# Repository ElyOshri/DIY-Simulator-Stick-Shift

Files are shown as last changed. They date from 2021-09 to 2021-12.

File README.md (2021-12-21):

# DIY-Simulator-Stick-Shift




A 3D Printed DIY Simulator Stick Shift Using Potentiometers And Arduino Nano Or ESP32

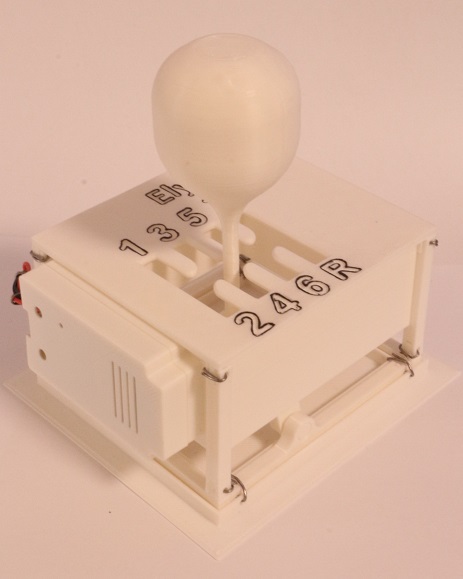
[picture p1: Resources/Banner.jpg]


## Topics
 - [Tutorial](https://github.com/ElyOshri/DIY-Simulator-Stick-Shift#tutorial)
 - [Tested Boards](https://github.com/ElyOshri/DIY-Simulator-Stick-Shift#tested_boards)
 - [Hardware](https://github.com/ElyOshri/DIY-Simulator-Stick-Shift#hardware)
 - [Credits](https://github.com/ElyOshri/DIY-Simulator-Stick-Shift#credits)

## Tutorial:
Download the hardware and firmware folders from [releases](https://github.com/ElyOshri/DIY-Simulator-Stick-Shift/releases). Start printing the parts from the hardware folder according to 3d printing list from [Hardware](#Hardware:) (some of the parts need support).

After you finish printing the Base, Hinge and the Main Stick you can start assembling the parts ([use this 3d model for reference](https://a360.co/3D5aO7Y)) ,
then insert the potentiometers to they're spots and wire them to your board according to this wiring diagram 
([Arduino Nano](https://user-images.githubusercontent.com/79017393/132395478-2bf8ad6f-0b95-429a-84c2-f516c4f6ddcb.png), 
[ESP32](https://user-images.githubusercontent.com/79017393/132395408-584d270a-1471-4dd1-976c-bccc9487b785.png) (for ESP32 use 3V3 instead of 5V)) You can look at the firmware for the exact pins that i used. 

After you wired everything up you can start uploading the firmware by choosing the correct file in the Firmware folder, changing the pins in the code, choosing your board and downloading all of the drivers and libraries necessary you can start uploading the firmware.(some boards needs you to press a button on them while uploading firmware)
* Note that for each board its going to be different and you may need to install libraries and drivers for your board (the links for the libraries and drivers are at the top of the file)
* In the serial monitor your need to set the baud rate to `115200` to see the correct values

Then check the serial monitor move the gear lever into each position and start assigning the rows values, then upload the firmware again and you should be finished.

**Here Are Some Good Tutorial To Help You With All Of This:**
- [Arduino Nano Original Guide](https://www.arduino.cc/en/Guide/ArduinoNano)
- [Arduino Nano Clone Driver](https://electropeak.com/learn/how-to-install-ch340-driver/)
- [ESP32 Driver And Guide](https://randomnerdtutorials.com/installing-the-esp32-board-in-arduino-ide-windows-instructions/)
- [Installing a Library](https://www.arduino.cc/en/guide/libraries)

## Tested_Boards:
```
* Arduino Nano
* ESP-WROOM-32
```

## Hardware:

* Arduino Nano or ESP32 (ESP32 for Bluetooth)
* WL b10k ohm Potentiometer (2x)
* 1mm or thinner metal wire (solder or paper clips can be used)
* 26 gauge or bigger electrical wire (2 meters should be enough)
* USB cable (depending on your board)
* Solder or a crimping set (JST connectors 5 pin JST-XH 2.54mm should work) 
* 3d printer filament (PLA or another ridged filament)

**3D Printed Parts:**
* Bottom Hinge
* Top Hinge
* Main Stick
* Base Right
* Base Left
* Base Top
* Base Bottom
* H Frame
* Right Frame / + Arduino Nano Case (depends on your board)
* Left Frame / + ESP32 Case (depends on your board)
* Base Attachment (optional)
* Case Cover ESP32/Arduino Nano (optional and depends on your board)

**Tools:**
* Soldering Iron / Crimping Set
* 3D Printer / A way to get the parts
* A computer with a USB port and the Arduino IDE app to program the board

## Credits
* Arduino Joystick Library (By: MHeironimus): https://github.com/MHeironimus/ArduinoJoystickLibrary
* ESP32 Gamepad Library (By: lemmingDev): https://github.com/lemmingDev/ESP32-BLE-Gamepad
* ESP32 Case (By: Antonio Garcia): https://www.thingiverse.com/thing:2071188
* Arduino Nano Case (By: Jonathan Prive): https://www.thingiverse.com/thing:4850125

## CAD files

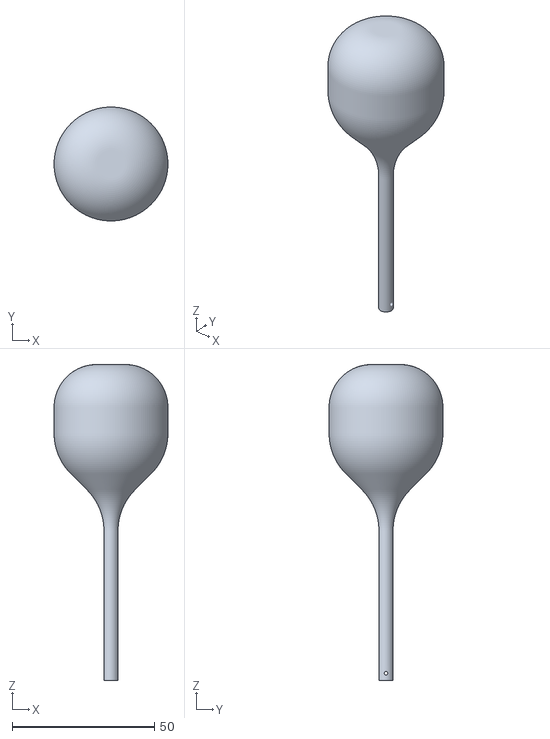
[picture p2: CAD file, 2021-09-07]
Hardware/Main Stick.stl
40.0 x 40.0 x 111.0

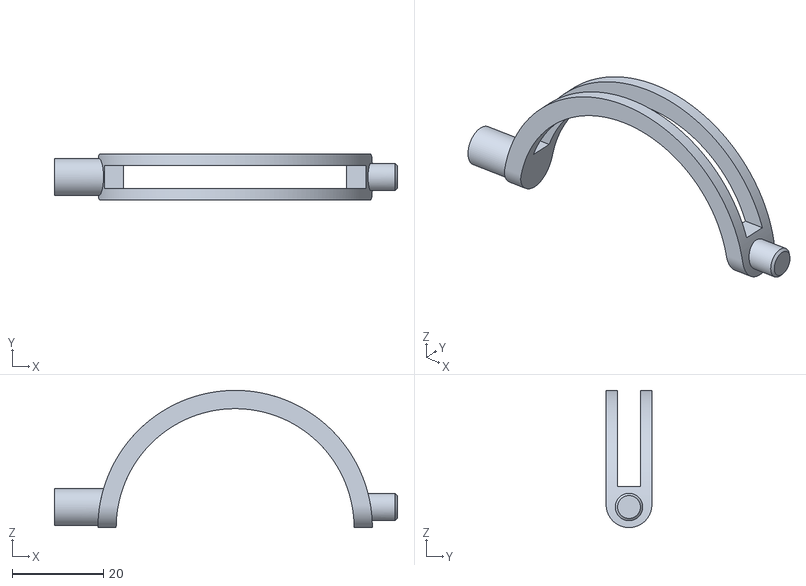
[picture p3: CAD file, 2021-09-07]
Hardware/Top Hinge.stl
75.0 x 10.0 x 30.0

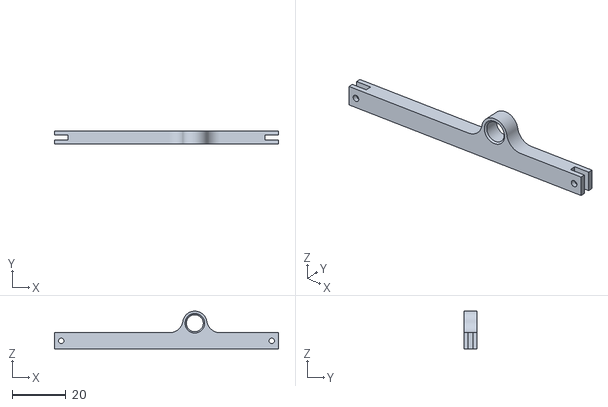
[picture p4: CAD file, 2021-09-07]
Hardware/Base Bottom.stl
83.0 x 5.00 x 14.0

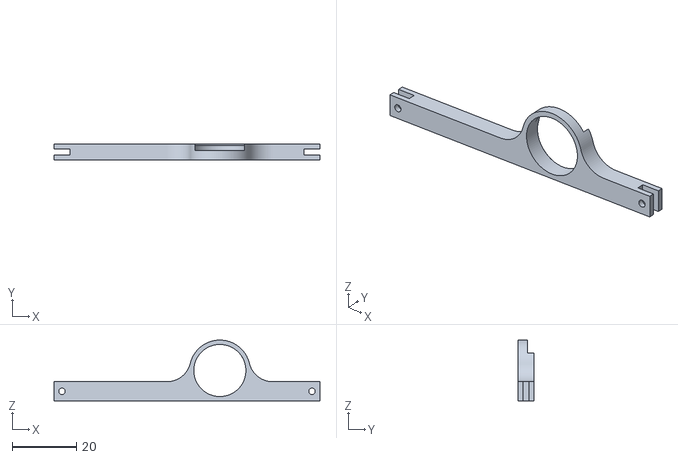
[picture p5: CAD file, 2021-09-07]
Hardware/Base Top.stl
83.0 x 5.00 x 19.0

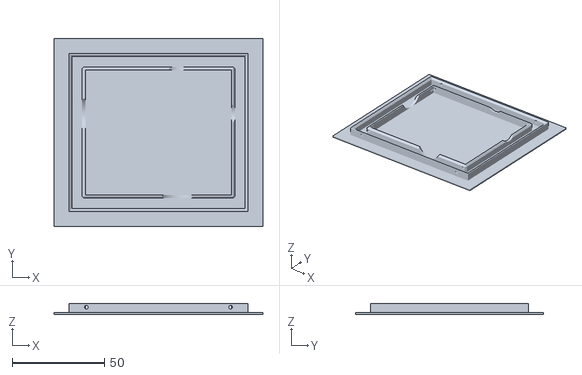
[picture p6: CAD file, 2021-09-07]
Hardware/Base Attachment.stl
113.0 x 101.5 x 6.00

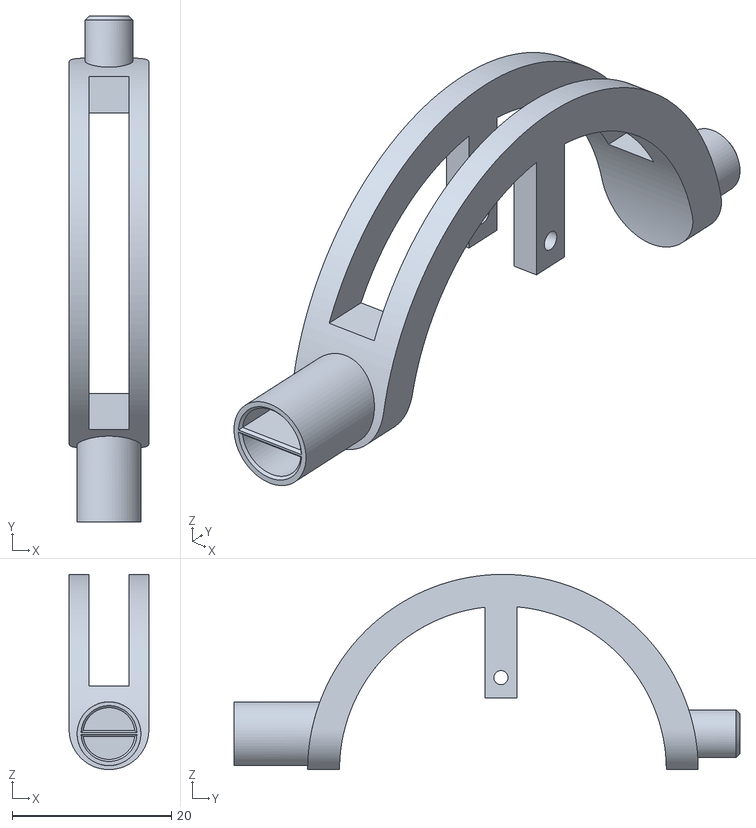
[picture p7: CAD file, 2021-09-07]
Hardware/Bottom Hinge.stl
10.0 x 63.5 x 24.5

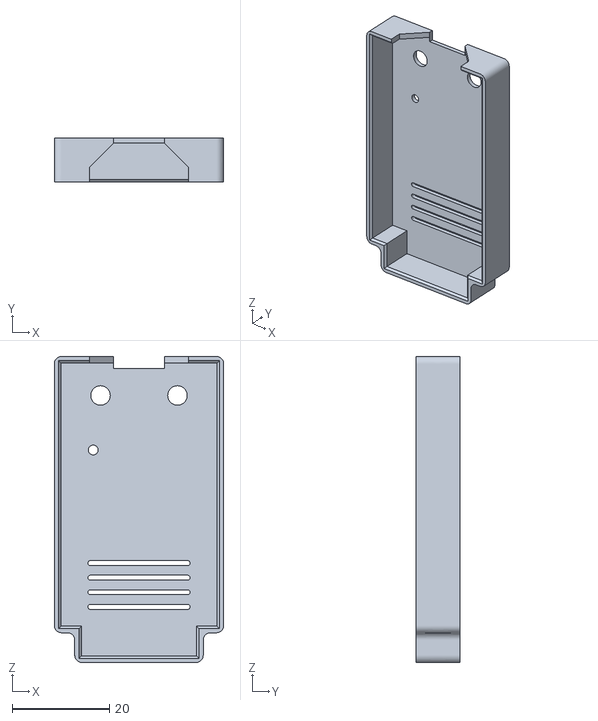
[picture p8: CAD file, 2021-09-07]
Hardware/ESP32 Case Cover.stl
34.8 x 9.00 x 62.8

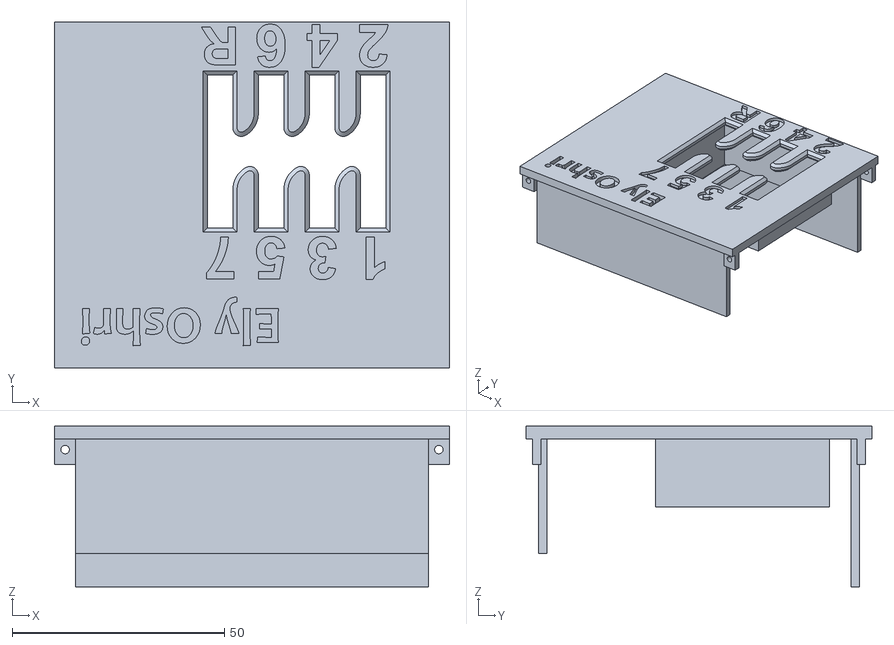
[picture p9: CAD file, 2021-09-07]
Hardware/H Frame.stl
93.0 x 81.5 x 37.8

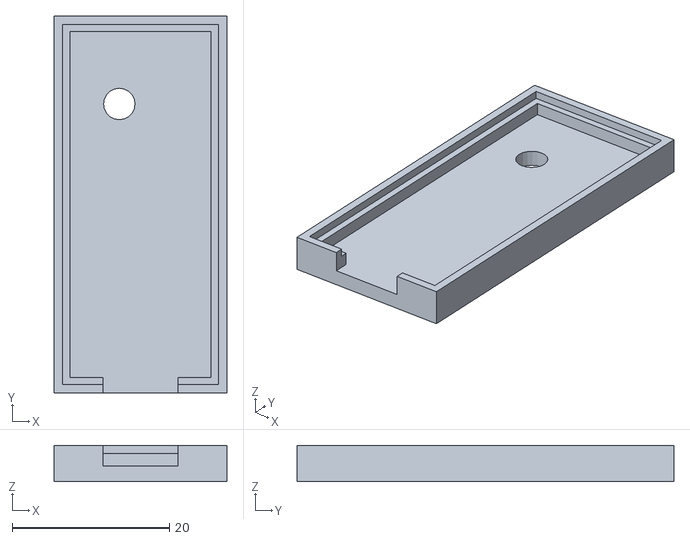
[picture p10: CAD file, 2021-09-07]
Hardware/Arduino Nano Case Cover.stl
22.0 x 48.0 x 4.60

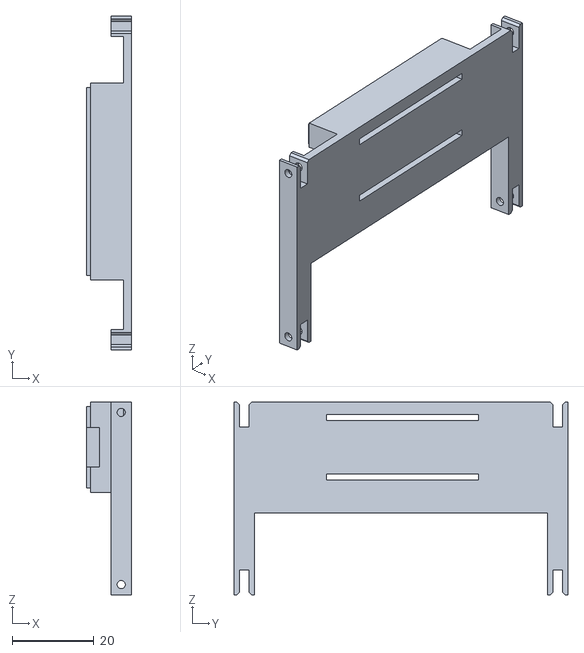
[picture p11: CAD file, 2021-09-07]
Hardware/Right Frame + Arduino Nano Case.stl
11.0 x 81.5 x 47.0

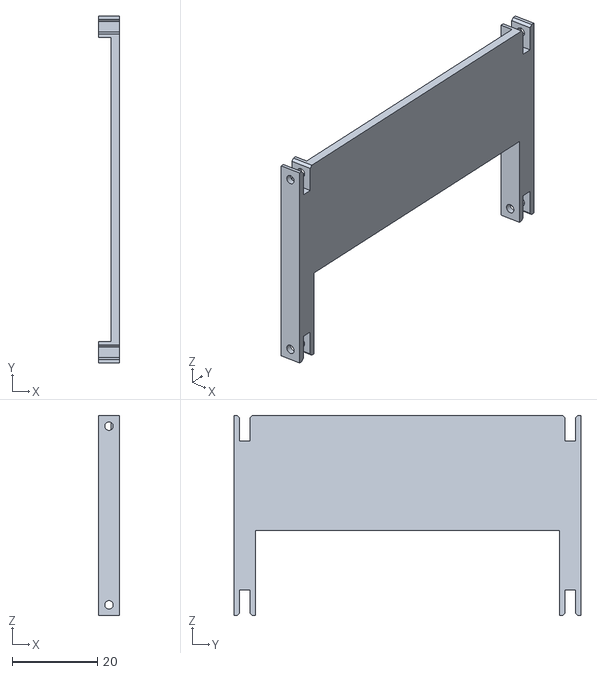
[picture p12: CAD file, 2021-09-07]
Hardware/Right Frame.stl
5.00 x 81.5 x 47.0

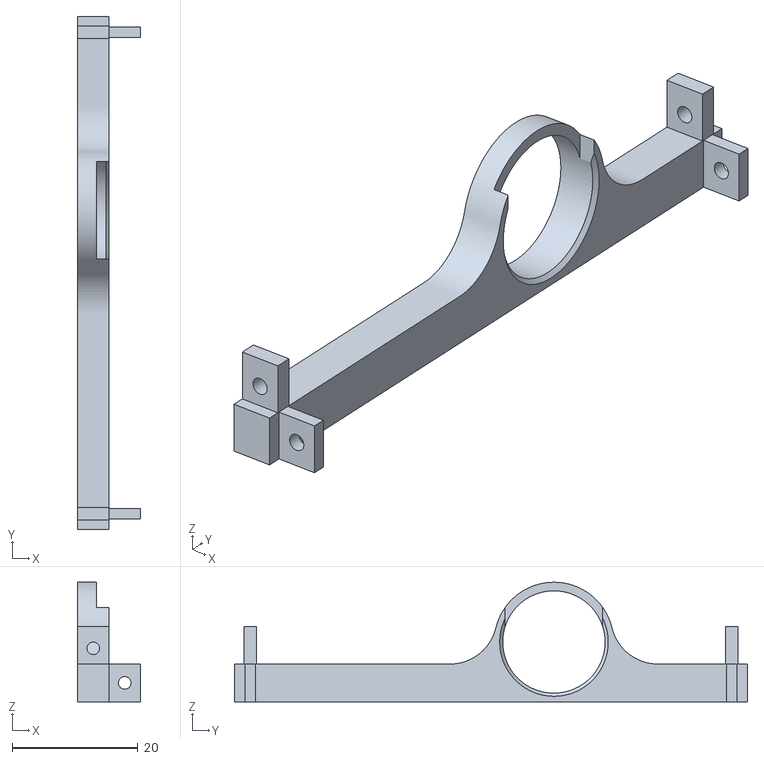
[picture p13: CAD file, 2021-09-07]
Hardware/Base Right.stl
10.0 x 81.5 x 19.0

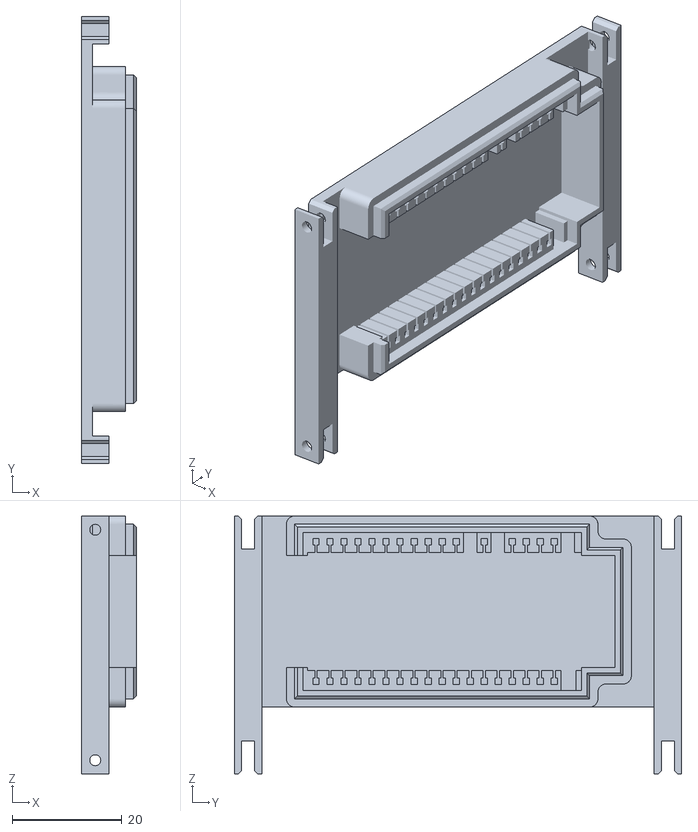
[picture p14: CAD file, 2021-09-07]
Hardware/Left Frame + ESP32 Case.stl
10.0 x 81.5 x 47.0

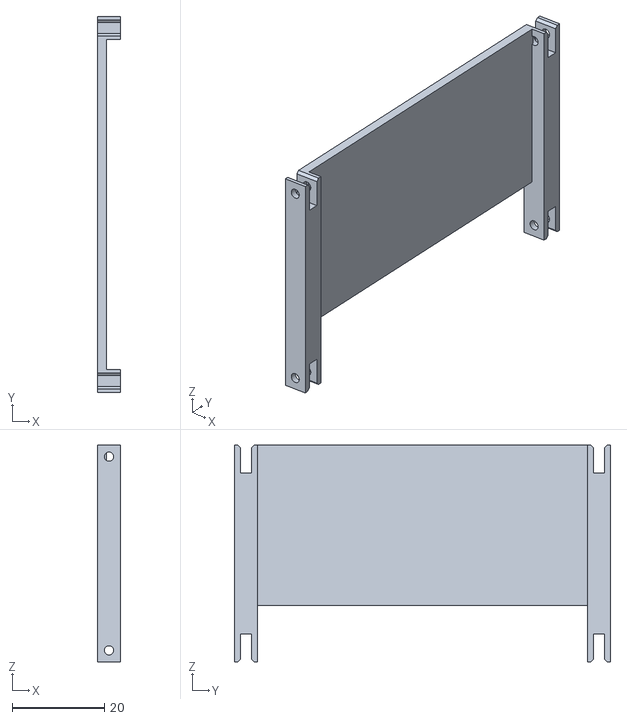
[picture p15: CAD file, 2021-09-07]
Hardware/Left Frame.stl
5.00 x 81.5 x 47.0

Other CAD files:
Hardware/Base Left.stl

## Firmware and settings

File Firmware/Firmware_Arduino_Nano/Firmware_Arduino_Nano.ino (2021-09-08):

//Arduino NANO CODE
//Joystick library is https://github.com/MHeironimus/ArduinoJoystickLibrary
//Arduino Nano Clone Driver: https://sparks.gogo.co.nz/ch340.html

#define MAX_POT_VALUE 1023 //max potentiometer value (only needed if you flip one of the axis)

#define POT_PIN_Y A6 
#define FLIP_Y false //if you wired the potentiometer wrong you can flip it (true or false)

#define POT_PIN_X A4
#define FLIP_X false //if you wired the potentiometer wrong you can flip it (true or false)

//Y Value
#define TOP_GEAR_ROW 415 //top row of gears max value (Y value < TOP_GEAR_ROW)
#define BOTTOM_GEAR_ROW 475 //bottom row of gears min value (Y value > BOTTOM_GEAR_ROW)


//X Value
#define FIRST_ROW_MAX 385 // 1 and 2 gears row max value (X value < FIRST_ROW_MAX)

#define SECOND_ROW_MIN 405 // 3 and 4 gears row min value (X value > SECOND_ROW_MIN)
#define SECOND_ROW_MAX 450 // 3 and 4 gears row max value (X value < SECOND_ROW_MAX)

#define THIRD_ROW_MIN 465 // 5 and 6 gears row min value (X value > THIRD_ROW_MIN)
#define THIRD_ROW_MAX 485 // 5 and 6 gears row max value (X value < THIRD_ROW_MAX)

#define FOURTH_ROW_MIN 500 // 7 and R/8 gears row max value (X value > FOURTH_ROW_MIN)



#include <Joystick.h>
Joystick_ Joystick;

int currentButton = 8;

int nutralCount = 0;

int potValueY;
int potValueX;


void setup() {
  Serial.begin(115200);
  Joystick.begin();
  Joystick.press(8);
}


void loop() {
  potValueY = analogRead(POT_PIN_Y);
  if (FLIP_Y) {
    potValueY = MAX_POT_VALUE - potValueY;
  }
  potValueX = analogRead(POT_PIN_X);
  if (FLIP_X) {
    potValueX = MAX_POT_VALUE - potValueX;
  }
  Serial.print("Y: ");
  Serial.print(potValueY);
  Serial.print(" X: ");
  Serial.print(potValueX);
  Serial.print(" Button: ");
  Serial.println(currentButton);

  if (Joystick.isConnected()) {
    if (potValueY < TOP_GEAR_ROW && potValueX < FIRST_ROW_MAX) {
      if (currentButton != 0) {
        Joystick.release(currentButton);
        Joystick.press(0);
        currentButton = 0;
        nutralCount = 0;
      }
    }
    else if (potValueY > BOTTOM_GEAR_ROW && potValueX < FIRST_ROW_MAX) {
      if (currentButton != 1) {
        Joystick.release(currentButton);
        Joystick.press(1);
        currentButton = 1;
        nutralCount = 0;
      }
    }
    else if (potValueY < TOP_GEAR_ROW && potValueX > SECOND_ROW_MIN && potValueX < SECOND_ROW_MAX) {
      if (currentButton != 2) {
        Joystick.release(currentButton);
        Joystick.press(2);
        currentButton = 2;
        nutralCount = 0;
      }
    }
    else if (potValueY > BOTTOM_GEAR_ROW && potValueX > SECOND_ROW_MIN && potValueX < SECOND_ROW_MAX) {
      if (currentButton != 3) {
        Joystick.release(currentButton);
        Joystick.press(3);
        currentButton = 3;
        nutralCount = 0;

      }
    }
    else if (potValueY < TOP_GEAR_ROW && potValueX > THIRD_ROW_MIN && potValueX < THIRD_ROW_MAX) {
      if (currentButton != 4) {
        Joystick.release(currentButton);
        Joystick.press(4);
        currentButton = 4;
        nutralCount = 0;
      }
    }
    else if (potValueY > BOTTOM_GEAR_ROW && potValueX > THIRD_ROW_MIN && potValueX < THIRD_ROW_MAX) {
      if (currentButton != 5) {
        Joystick.release(currentButton);
        Joystick.press(5);
        currentButton = 5;
        nutralCount = 0;
      }
    }
    else if (potValueY < TOP_GEAR_ROW && potValueX > FOURTH_ROW_MIN) {
      if (currentButton != 6) {
        Joystick.release(currentButton);
        Joystick.press(6);
        currentButton = 6;
        nutralCount = 0;
      }
    }
    else if (potValueY > BOTTOM_GEAR_ROW && potValueX > FOURTH_ROW_MIN) {
      if (currentButton != 7) {
        Joystick.release(currentButton);
        Joystick.press(7);
        currentButton = 7;
        nutralCount = 0;
      }
    }
    else {
      nutralCount = nutralCount + 1;
      if (pressed == true && currentButton != 8 && nutralCount > 5) {
        Joystick.release(currentButton);
        Joystick.press(8);
        currentButton = 8;
      }
    }
  }
  delay(100);
}

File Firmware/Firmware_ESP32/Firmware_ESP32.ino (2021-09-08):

//ESP32 CODE
//Gamepad library is https://github.com/lemmingDev/ESP32-BLE-Gamepad
//ESP32 Driver: https://randomnerdtutorials.com/installing-the-esp32-board-in-arduino-ide-windows-instructions/

#define MAX_POT_VALUE 4095 //max potentiometer value (only needed if you flip one of the axis)

#define POT_PIN_Y 35 
#define FLIP_Y false //if you wired the potentiometer wrong you can flip it (true or false)

#define POT_PIN_X 33
#define FLIP_X false //if you wired the potentiometer wrong you can flip it (true or false)

//Y Value
#define TOP_GEAR_ROW 1650 //top row of gears max value (Y value < TOP_GEAR_ROW)
#define BOTTOM_GEAR_ROW 1900 //bottom row of gears min value (Y value > BOTTOM_GEAR_ROW)


//X Value
#define FIRST_ROW_MAX 1550 // 1 and 2 gears row max value (X value < FIRST_ROW_MAX)

#define SECOND_ROW_MIN 1625 // 3 and 4 gears row min value (X value > SECOND_ROW_MIN)
#define SECOND_ROW_MAX 1800 // 3 and 4 gears row max value (X value < SECOND_ROW_MAX)

#define THIRD_ROW_MIN 1850 // 5 and 6 gears row min value (X value > THIRD_ROW_MIN)
#define THIRD_ROW_MAX 1950 // 5 and 6 gears row max value (X value < THIRD_ROW_MAX)

#define FOURTH_ROW_MIN 2000 // 7 and R/8 gears row max value (X value > FOURTH_ROW_MIN)



#include <BleGamepad.h>
BleGamepad bleGamepad("Sim Stick Shift", "Ely Oshri", -1);

bool pressed = true;
int currentButton = 9;

int nutralCount = 0;

int potValueY;
int potValueX;


void setup() {
  Serial.begin(115200);
  bleGamepad.begin();
  bleGamepad.press(BUTTON_9);
}


void loop() {
  potValueY = analogRead(POT_PIN_Y);
  if (FLIP_Y) {
    potValueY = MAX_POT_VALUE - potValueY;
  }
  potValueX = analogRead(POT_PIN_X);
  if (FLIP_X) {
    potValueX = MAX_POT_VALUE - potValueX;
  }
  Serial.print("Y: ");
  Serial.print(potValueY);
  Serial.print(" X: ");
  Serial.print(potValueX);
  Serial.print(" Button: ");
  Serial.println(currentButton);

  if (bleGamepad.isConnected()) {
    if (potValueY < TOP_GEAR_ROW && potValueX < FIRST_ROW_MAX) {
      if (pressed == true && currentButton != 1) {
        bleGamepad.release(currentButton);
        bleGamepad.press(BUTTON_1);
        pressed = true;
        currentButton = 1;
        nutralCount = 0;
      }
    }
    else if (potValueY > BOTTOM_GEAR_ROW && potValueX < FIRST_ROW_MAX) {
      if (pressed == true && currentButton != 2) {
        bleGamepad.release(currentButton);
        bleGamepad.press(BUTTON_2);
        pressed = true;
        currentButton = 2;
        nutralCount = 0;
      }
    }
    else if (potValueY < TOP_GEAR_ROW && potValueX > SECOND_ROW_MIN && potValueX < SECOND_ROW_MAX) {
      if (pressed == true && currentButton != 3) {
        bleGamepad.release(currentButton);
        bleGamepad.press(BUTTON_3);
        pressed = true;
        currentButton = 3;
        nutralCount = 0;
      }
    }
    else if (potValueY > BOTTOM_GEAR_ROW && potValueX > SECOND_ROW_MIN && potValueX < SECOND_ROW_MAX) {
      if (pressed == true && currentButton != 4) {
        bleGamepad.release(currentButton);
        bleGamepad.press(BUTTON_4);
        pressed = true;
        currentButton = 4;
        nutralCount = 0;

      }
    }
    else if (potValueY < TOP_GEAR_ROW && potValueX > THIRD_ROW_MIN && potValueX < THIRD_ROW_MAX) {
      if (pressed == true && currentButton != 5) {
        bleGamepad.release(currentButton);
        bleGamepad.press(BUTTON_5);
        pressed = true;
        currentButton = 5;
        nutralCount = 0;
      }
    }
    else if (potValueY > BOTTOM_GEAR_ROW && potValueX > THIRD_ROW_MIN && potValueX < THIRD_ROW_MAX) {
      if (pressed == true && currentButton != 6) {
        bleGamepad.release(currentButton);
        bleGamepad.press(BUTTON_6);
        pressed = true;
        currentButton = 6;
        nutralCount = 0;
      }
    }
    else if (potValueY < TOP_GEAR_ROW && potValueX > FOURTH_ROW_MIN) {
      if (pressed == true && currentButton != 7) {
        bleGamepad.release(currentButton);
        bleGamepad.press(BUTTON_7);
        pressed = true;
        currentButton = 7;
        nutralCount = 0;
      }
    }
    else if (potValueY > BOTTOM_GEAR_ROW && potValueX > FOURTH_ROW_MIN) {
      if (pressed == true && currentButton != 8) {
        bleGamepad.release(currentButton);
        bleGamepad.press(BUTTON_8);
        pressed = true;
        currentButton = 8;
        nutralCount = 0;
      }
    }
    else {
      nutralCount = nutralCount + 1;
      if (pressed == true && currentButton != 9 && nutralCount > 5) {
        bleGamepad.release(currentButton);
        bleGamepad.press(BUTTON_9);
        pressed = true;
        currentButton = 9;
      }
    }
  }
  delay(100);
}
